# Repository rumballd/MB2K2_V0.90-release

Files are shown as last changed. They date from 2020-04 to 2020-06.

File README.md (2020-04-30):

# MB2K2_V0.90 release

Microbox 2K2 (MB2K2). 

The MB2K2 is a hardware based emulator built around the Xmos XU216 SoC where each of the 16 RISC cores in the SoC map onto the individual LSI chips of the system being emulated, CPU, PIA, ACIA, RTC etc. The PCB has VGA based video together with a PS/2 keyboard interface and USB for power and two virtual serial ports to a host computer. 

Initially I’ve used it to emulate an old 1982 era 6809/Flex single board computer design of mine (Microbox 2) but there’s nothing to stop the emulation of other processors and LSI devices by using a low cost JTAG interface and free toolchain from Xmos. If enough folks are interested I should be able to order a batch of blank PCBs.

The hardware is complete and the initial firmware supports:-

* MC6809 processor emulation running at approx 8MHz equiv (ie 4x faster than the original)
* 64KB of 6809 RAM with MON09 and Flex in ‘ROM'
* 200KB ramdisk + 1MB+ promdisk
* WD2123 DUART emulation with twin serial ports to the host computer as VCPs via USB, one can be used with FlexNet for remote storage
* MC146818 RTC emulation via a physical battery backed RTC/PRAM on the PCB
* MC6821 PIA emulation for the MB2’s bell and option switches and PS/2 keyboard interface (replaces the MB2’s parallel keyboard)
* uPD7220A hardware graphics accelerator emulation with output as 768x576 ‘VGA’
* PS/2 keyboard interface 

Not in the initial release but ‘hardware ready’ is a 3 1/2” floppy disk interface emulating the WD1770 FDC.

This all fits on a 80x80mm double sided 4 layer PCB which is designed to be assembled by hand (few fine pitch components etc).

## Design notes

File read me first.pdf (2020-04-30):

Version 0.9 30th April 2020

### Microbox 2K2 distribution 0.9 April 2020

This package should contain the following folders :-

* docs | - MB2K2 user notes, quick start guide and FLEX manuals.
* firmware | - XU216 firmware project, data sheets and app notes.
* hardware | - PCB fabrication files and component data sheets.
* MB2K2 source | - 6809 source plus MB2K2_SRC and PROMdisk disk images.

History
2020-04-30 | ver 0.9 | First release to the outside world.

Known Issues

Todo List

This early release of the MB2K2 firmware is fully functional and runs the MB2 graphics demo software, but there are some unfinished parts and in later releases I hope to :-

- Improve the documentation!
- Improve the uPD7220A emulation for greater compatibility with MB2 software.
- Port the schematic/PCB design from Altium into KiCad so that the hardware can be changed with free and open source tools.
- Implement the WD170 floppy disk controller

This project does not contain polished or shipping quality code, so use entirely at you own risk. As this is the first release there may be some unknown dependences on my particular build environment.

The project is covered under the permissive version of the CERN Open Hardware Licence Version 2 a copy of which is part of the package.

If you have any problems with the build, find any bugs, have suggestions for features and improvements etc, please email me at david@rumball.org.uk

Have Fun!

David Rumball
Hinxworth, UK.

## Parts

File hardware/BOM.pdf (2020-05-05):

Designator | Descrip-on | Manufacturer | ManufacturerPN | Quan-ty
BT1 | CR1225 coin cell holder | Keystone | 3001 | 1
C1, C3, C5 | 4.7uF 0805 Ceramic Capacitor, 10%, 25V | Generic | | 3
C2, C7, C9, C10, C13, C14, C17, C18, C19, C20, C21, C22, C23, C24, C25, C26, C27, C28, C29, C30, C32, C33, C34 | 100nF 0805 Ceramic Capacitor, 10%, X5R, 25V | Generic | | 23
C4 | 2.2uF 0805 Ceramic Capacitor, 10%, 25V | Generic | | 1
C6 | 22uF 0805 Ceramic Capacitor, 10%, 6.3V | Generic | | 1
C8 | 10nF 0805 Ceramic Capacitor, 20%, X7R, 50V | Generic | | 1
C11, C12 | 4p7 0805 Ceramic Capacitor, 50V | Generic | | 2
C15, C16 | 1nF 0805 Ceramic Capacitor, 5%, 50V | Generic | | 2
C31 | 1uF 0805 Ceramic Capacitor, 10%, 16V | Generic | | 1
C35 | 100p 0805 Ceramic Capacitor, 50V | Generic | | 1
CN1 | Box header 2.54mm Ver-cal 20 way | Molex | 70246-2004 | 1
D1 | LED 0805 White | Generic | | 1
D2, D4, D6 | LED 0805 Red | Generic | | 3
D3, D5, D7 | LED 0805 Green | Generic | | 3
D8 | LED 0805 Blue | Generic | | 1
D9 | Dual ESD protec-on diode SMD | Nexperia | PRTR5V0U2X,215 | 1
D10 | Diode SchoXky, 1A, 40V, SOD-123-2 | ON Semiconductor | SS14FL | 1
J1 | VGA HD-25 connector RA through hole | EDAC | 634-015-274-992 | 1
J2 | MIni DIN 6 pin through hole | TE | 5749180-1 | 1
J3 | Box header 2.54mm Ver-cal 34 way | Molex | 70246-3404 | 1
J4 | USB type B connector RA through hole | Mul-comp | USB-B-S-RA | 1
J5 | Ver-cal Pin Header Pitch 0.1", Single Row, 3 pins | Wurth Elektronik | 61300311121 | 1
L1 | Inductor, Mul-layer, 2.2uH, 3.1A Isat, SMD | Vishay Dale | IFSC1515AHER2R2M01 | 1
LS1 | 3V Buzzer through hole | IMO | 41.S78P030A-LF | 1
P1, P2 | Ver-cal Pin Header Pitch 0.1", Single Row, 5 pins | Wurth Elektronik | 61300511121 | 2
R1, R2, R3, R4, R17, R27, R35, R36, R39 | 330R 0805 Chip Resistor | Generic | | 9
R5, R9, R14, R40, R42 | 4K7 0805 Chip Resistor | Generic | | 5
R6 | 17K8 0805 Chip Resistor | Generic | | 1
R7 | 3K0 0805 Chip Resistor | Generic | | 1
R8, R13, R15, R16, R19, R21, R22, R23, R24, R25, R26, R38, R43, R44, R45, R48 | 10K 0805 Chip Resistor | Generic | | 16
R10, R41 | 100K 0805 Chip Resistor | Generic | | 2
R11, R12, R18, R20, R28 | 1K0 0805 Chip Resistor | Generic | | 5
R29, R31, R33, R49, R58, R59 | 33R 0805 Chip Resistor | Generic | | 6
R30, R32, R34 | 100R 0805 Chip Resistor | Generic | | 3
R37, R46, R51, R55, R56, R57 | 0R 0805 Chip Resistor | Generic | | 6
R47 | 4R7 0805 Chip Resistor | Generic | | 1
R50 | 43R 0805 Chip Resistor | Generic | | 1
R52, R53, R54 | 75R 0805 Chip Resistor | Generic | | 3
SW1 | 4 way DIP switch, through hole | CTS | 210-4MS | 1
SW2 | Tac-le Switch, SPST-NO, 0.05A, 12V | E-Switch | TL1014AF160QG | 1
TR1, TR2, TR3 | N Channel MOSFET 20V SOT23 | Taiwan Semiconductors | TSM2302CX | 3
U1 | SP6205EM5-L-3-0 500mA Low Dropout Voltage Regulator | Exar | SP6205EM5-L-3-3/TR | 1
U2 | Switching regulator, 1.5 A, adjustable, step-down, 6-Pin DFN | STMicroelectronics | ST1S06PUR | 1
U3 | xCORE-200 XU series 512 kB RAM TQFP128 | XMOS | XU216-512-TQ128-C20 | 1
U4 | Memory, Flash, QSPI, 32Mb, SOIC-8 | ISSI | IS25LQ032B-JNLE | 1
U5 | Voltage Detector, 0.9V, Programmable Delay, OD, SOT23-5 | ON Semiconductor | NCP303LSN09T1G | 1
U6 | BaXery-Backed I2C RTC + SRAM & EEPROM | Microchip | MCP79410-I/SN | 1
U7, U8 | Hex OD buffer SOIC-14 | Texas Instruments | SN74LVC07AD | 2
U9 | Quad Buffer 3-State SOIC-14 | Texas Instruments | SN74LVC125AD | 1
X1 | SMD Crystal, 32.768kHz | Epson Toyocom | FC-135 32.7680KA-AC | 1
X2 | XTAL Osc XO 24MHz CMOS | Abracon LLC | ASE-24.000MHZ-LC-T | 1

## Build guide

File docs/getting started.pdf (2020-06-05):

Microbox 2K2 User Guide | Version 0.9 30th April 2020

### Microbox 2K2 ‘getting started’ guide

Introduction

This guide covers the initial set up and basic operation of the Microbox 2K2 (MB2K2) including the installation of the Xmos xTIMEcomposer toolchain which is used to flash and reprogram the system.

The MB2K2 is based around a single PCB that carries the circuitry for the complete system requiring only the addition of a 5V USB power supply, standard PS/2 compatible keyboard and VGA monitor. Alternatively the MB2K2 may just be plugged into the USB port of a host computer with a terminal application running on the host providing the user interface.

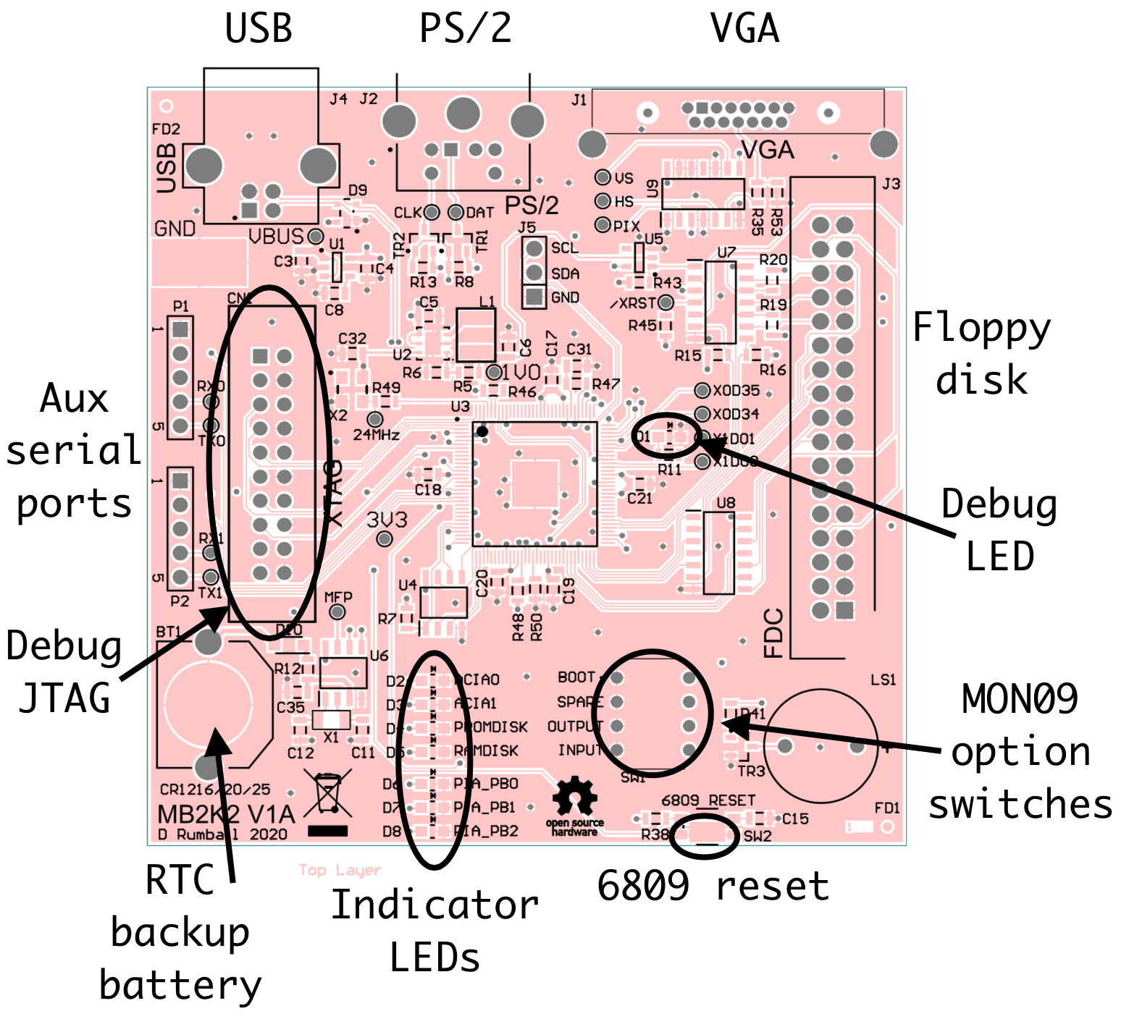
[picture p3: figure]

Connector, switches and LED locations

Initial set up

The MB2K2 is powered entirely via it’s USB connector and requires a notional 5V supply at a maximum of 250mA (approx 150mA nominal) to its ‘type B’ connector. This is well within the capability of most standard computer USB ports. If the MB2K2 is to be used stand alone without a host connection a standard USB charger may be used instead.

If the MB2K2 is connected to a host computer for power and control then no further set up is required other wise a standard PS\2 style keyboard and VGA compatible monitor need to be connected. Note that the keyboard is powered directly from the board’s USB port and so the keyboard will increase the power draw of the system. The horizontal display rate of the MB2K2 is approximately 35KHz and the frame rate 56Hz which should be compatible with the majority of modern monitors.

The MB2K2 uses a battery backed real time clock for time date and persistent storage of settings. The battery is a standard 3V Lithium coin cell and the battery holder can accept CR1216 CR1220 or CR1225 batteries.

Before first powering on, set the MON09 option switches according to the required input and display and set switch 0 ‘off’ so that the system starts up in MON09.

Switch 0 | Sets the auto boot function. on = Auto boot into FLEX on reset off = run MON09 on reset
Switch 1 | (not used in this build)
Switch 2 | Sets the initial output port to be used after reset on = PORT 1 (serial port 0) - USB off = PORT 0 (GDC screen)
Switch 3 | Sets the initial input port to be used after reset on = PORT 1 (serial port 0) - USB off = PORT 0 (PS/2 keyboard)

After applying power if all is well then the display should show the MON09 startup banner followed by the command prompt and a flashing cursor:-

+++ MON09 Ver 6.0 D.A.Rumball 2020 +++
=>

Note that if this is the first power up after inserting the battery or if the battery is not present then a warning will be shown and the default settings loaded into the RTC.

At the MON09 prompt a two character command can be issued and these commands are detailed in section 5 of the user guide.

To boot into FLEX type ‘BO’, FLEX will be loaded, the ‘TTYSET’ and ‘ASN’ parameters will be set, the time and date shown and the FLEX ‘+++’ prompt will appear. Note that if switch 3 of the option switches is ‘on’ then the MB2K2 will boot immediately into FLEX on power up.

The standard firmware of the MB2K2 includes a pre-installed PROMdisk of FLEX commands and utilities and the PROMdisk contents are detailed in appendix 6 of the User Guide. The default work disk is a (volatile) RAMdisk. Further disk images may be connected via USB and FlexNet.
FlexNet and remote disk images

The MB2K2 has drivers in ROM that are compatible with the FlexNet protocol. FlexNet allows FLEX disk images on a computer connected to the MB2K2 via USB to look like a disk drive to FLEX. To use this facility it’s necessary to install the FlexNet server software on the connected system. The FlexNet software for windows can be downloaded from http://www.evenson-consulting.com/. (http://www.evenson-consulting.com/) Details of the FLEX utilities that work with FlexNet are given in section 6 of the user guide.

Presently FlexNet is only available for Windows only but the plan is to ship cross platform versions of the FlexNet server etc in a later version of the MB2K2 release.

Building and flashing the firmware

Flashing the MB2K2’s firmware requires the installation of the free Xmos xTIMEcomposer toolchain (version 14.4.1) and obtaining an ‘XTAG’ (https://www.xmos.com/download/xTAG-3-Hardware-Manual(1.0).pdf) USB debug interface. The toolchain may be downloaded directly from Xmos at the tools download (https://www.xmos.com/software/tools/) page and the XTAG interface is readily available from several suppliers world wide for about $20, see Octopart (https://octopart.com/xa-xtag-xmos-52441747?r=sp) for details.

Documentation for the xTIMEcomposer tools is in the ‘data sheets & app notes etc’ folder in the firmware folder and covers importing project, the IDE, building the project and flashing. Details on building MON09 and modifying other parts of the MB2K2 firmware may be found in section 4 of the MB2K2 User Guide.

The MB2K2 can be flashed from xTIME composer or the command line tools but whichever route is taken it is necessary to specify these options:-

--no-compression
--boot-partition-size 0x100000
--data <location of promdisk.dsk file>

In the default build, the binaries (.xe files) are in the ‘release’ and ‘debug’ folders in the ‘bin’ folder in the firmware project folder whilst the PROMdisk disk image is in the ‘promdisk’ folder.

A more detailed set of instructions for building and flashing the firmware can be found in the ‘Firmware Build and Flashing Guide’ contained in the documentation folder.

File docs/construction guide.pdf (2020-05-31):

Version 0.9 30th April 2020

### Microbox 2K2 Construction guide

Introduction

This document contains some brief notes to assist during the assembly of the MB2K2 PCB. It assumes that the reader has some experience with fine pitch SMD soldering, if not don’t panic as there are any number of online resources and YouTube videos that go over the basics.

As with all SMD assembly it’s important to follow good safety procedures particularly to ensure that you have good protection from the fumes generated from soldering and from any hot solder splashes, again there is a wealth of online information concerning protection from these and other hazards, follow it!

The tips and suggestions below are intended to be guidelines and don’t need to be followed slavishly, if you have a better way of doing things then by all means use it.

The PCB has been designed with an eye towards manual assembly and has a number of features to simplify the process. It’s entirely possible to assemble the board using just a temperature controlled soldering iron and without needing to use a hot air gun or reflow plate.

BOM
The component BOM is given in the hardware folder of the release package. For convenience it’s also accessible as a shared ‘live’ BOM on Octopart. (https://octopart.com/bom-tool/GZSDr5Fk) At the time of writing all the components are really available and the total BOM cost is < $50.

Construction notes

- R51 is no fit
- R55-57 are optional components
- The surface finish of the PCB is ENIG (https://en.wikipedia.org/wiki/Electroless_nickel_immersion_gold) as this eases the soldering of the fine pitch components. With this finish it’s important to clean the PCB thoroughly before assembly and to use a good quality flux. I’ve found that one of the no clean ‘gel’ fluxes gives the best results.
- Assemble the 3.3V and 1.0V power power supply components first and test that these are working correctly before proceeding with the rest of the assembly. This can save some expensive problems later on. The switch mode regulator chip U2 has a ‘hidden’ ground pad underneath its package. So that this device can be attached without reflow there is a large via in the PCB underneath the parts and this allows the hidden pad to be soldered from the bottom of the PCB. This feature also has the side effect of forming a good heat sink to the inner layers of the PCB although in practice this isn’t needed as the design runs very cool in use as this thermograph shows:-

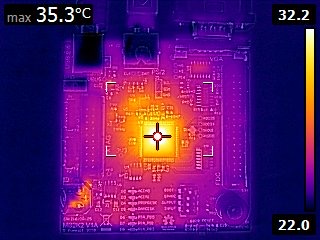
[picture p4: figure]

- The XU216 should be added next, this is probably the most difficult part. Be sure to leave the XU216 in its moisture sealed packaging until just before assembly as the part is prone to ‘popcorning’ (https://en.wikipedia.org/wiki/Moisture_sensitivity_level) if left in a humid atmosphere too long. The leads of this part are quite fragile, if possible handle just with a vacuum pencil (http://www.apple.com/uk) to avoid touching the leads.

Use plenty of flux; this is where the gel flux is handy because it holds the part in place but still allows fine adjustments of position. (Don’t forget to put some flux on the ground pad in and around the via). Check that pin 1 is in the correct place! (there is a flat corner and depression marking on the part and a dot on the PCB to show the location of pin one). When the part is correctly positioned, tack down one lead near a corner and check the alignment again, if ok tack a pin on the opposite corner.

Because of the fine pitch of the leads on the part, the best way to solder the leads isn’t to use the traditional technique of applying the solder to the joint, instead it’s better to apply a small amount of solder to the iron tip and apply this to the very end of the pin allowing the solder to wick along the pad to form the joint. The PCB features solder mask slivers between the pads (this would not normally be a good idea in a mass production PCB) which helps discourages the solder from bridging between pins and if any solder bridges do form the solder mask assists clearing these with solder wick.

In the same manner as the switch mode regulator the XU216 has a hidden pad underneath the device which is its only connection to ground. This pad carries all of the logic and I/O current so it’s important to ensure that a good connection is made. As before there is a large via which is used to allow access to the ground pad from the rear of the PCB so when the signal leads are soldered then the ground connection can be made. Use plenty of flux here and flood solder into the via. Heat will tend to flow into the internal planes of the PCB so use a hot iron and beware of forming a ‘cold’ solder joint. When complete it should look something like this :-

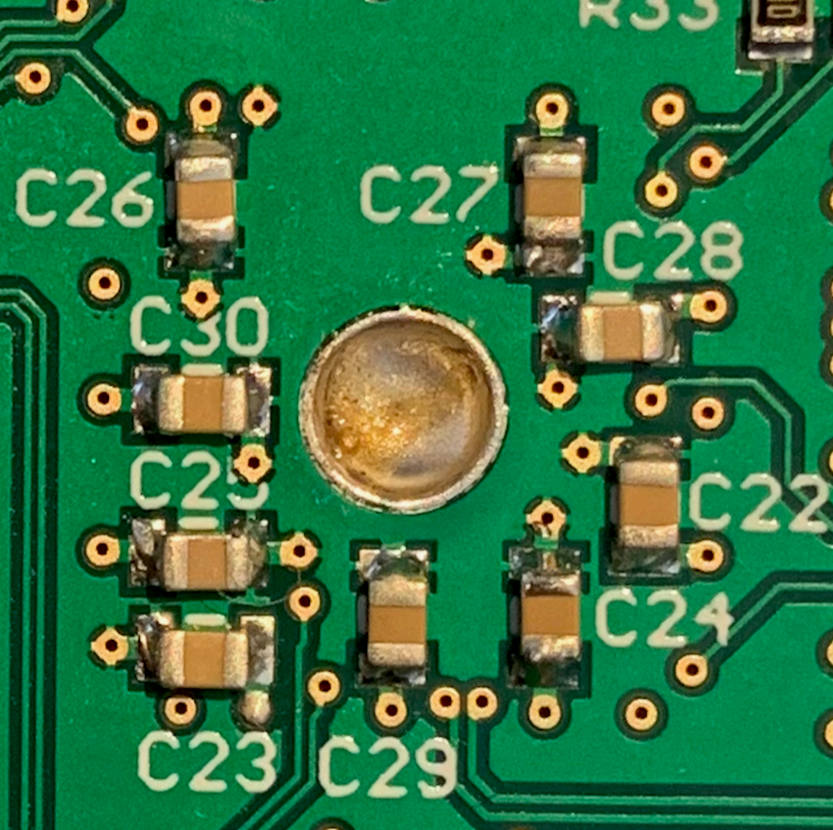
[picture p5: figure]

- After the XU216 is in place, place the other SMD components. For the discrete parts flux both pads then tin one of the pads. Then slide the part into place with fine point tweezers whilst melting the solder to make the first joint and then solder the other end. In practice this takes less time to do than to describe. I find that it’s easiest to work down the BOM placing all the instances of a particular component value in one pass.
- After placing the SMD parts place the through hole parts last of all and give the PCB a good clean with IPA and an old toothbrush.

Initial testing

- Don’t install the battery until after the firmware is flashed.
- Briefly apply power to the board and check current draw, it should be in the region of 100mA - 150mA, much greater than this indicates a short somewhere or a reversed IC. If the initial ‘smoke test’ is OK check that the 3.3V and 1V power rails are correct.
- If a scope is available check that the 24MHz clock is present and that reset is asserted following power up.

Flashing the firmware

Flashing the MB2K2’s firmware requires the installation of the free Xmos xTIMEcomposer toolchain (version 14.4.1) and obtaining an ‘XTAG’ (https://www.xmos.com/download/xTAG-3-Hardware-Manual(1.0).pdf) USB debug interface. The toolchain may be downloaded directly from Xmos at the tools download (https://www.xmos.com/software/tools/) page and the XTAG interface is readily available from several suppliers world wide for about $20, see Octopart (https://octopart.com/xa-xtag-xmos-52441747?r=sp) for details.

Documentation for the xTIMEcomposer tools is in the ‘data sheets & app notes etc’ folder in the firmware folder and covers importing project, the IDE, building the project and flashing. It may be also necessary to install the Java runtime

Download the latest MB2K2 release package from GitHub, (https://github.com/rumballd/MB2K2_V0.90-release.git) unzip the project folder located in MB2K2_V0.90-release-master\firmware and locate the binary images in MB2K2\bin within the project.

Power on the MB2K2 and connect the XTAG to the board. (the XTAG may be safely connected or disconnected to a powered MB2K2) then open up the Xmos command line interface installed as part of xTIMEcomposer in the earlier step and use the following command:-

xrun -l

This command looks for the XTAG connector then reports on the connected device. The command should report something like :-

Available XMOS Devices
ID | Name | Adapter ID | Devices
0 | XMOS XTAG-3 | ZByhc2hJ | O[0]

if the command reports ‘none’ for the devices then there is a hardware fault with the board. If the power supplies and 24MHz clock are OK then this will most likely be an issue with a bad solder joint on the XU216 so check the pin connections and the ground connection under the PCB.

If all is well then the firmware may be flashed with the ‘xflash’ command thus:-

xflash -—verbose -—no-compression -—factory <image.xe> --boot-partition-size 0x80000 --data <promdisk.dsk>

where
<image.xe> is the path to the image file
use MB2K2\bin\mb2k2_debug_usb.xe as the default

<promdisk.dsk> is the path to the promdisk image
use MB2K2/promdisk/MB2K2PD.dsk as the default

After about 30 seconds or so the flashing will begin with a series of messages of the form ‘site 0 write’ followed by an incrementing address as each flash block is written. With the current build and promdisk the block address will run up to about 0x00110500.

After the flashing process is complete the MB2K2 will restart and you should see the debug LED (to the right hand side of the XU216) flashing on and off in a ‘breathing’ pattern. This is the sign that the firmware is working correctly. Power down and insert the battery (noting polarity).

Congratulations on a successful build!

Connect a VGA compatible monitor and PS/2 keyboard and boot into FLEX with the ‘BO’ command in MON09 then set the current date and time with the SETTIME command.

This completes the initial testing of your MB2K2, so make yourself a nice cup of tea (or whatever you prefer), sit down with your feet up, type DEMO and watch the pretty graphics!

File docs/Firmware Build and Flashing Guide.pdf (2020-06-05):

Microbox 2K2 User Guide | Version 0.9 30th April 2020

### MB2K2 Firmware Build and Flashing Guide

Introduction

This guide covers the installation of the Xmos xTIMEcomposer toolchain which is used to flash and reprogram the system together with a walkthrough on building the firmware and flashing this to the hardware.

Prerequisites

In order to talk to the XU216’s JTAG interface for debugging and programming the on board flash memory it will be necessary to obtain an Xmos ‘XA-XTAG’ USB debug adaptor. These are really available from component distributors such as Digi-Key for about $20. Octopart has a list of distributors and stock here. (https://octopart.com/xa-xtag-xmos-52441747?r=sp) The XTAG plugs vertically into the 20 pin header on the MB2K2 PCB.

Step by step guide

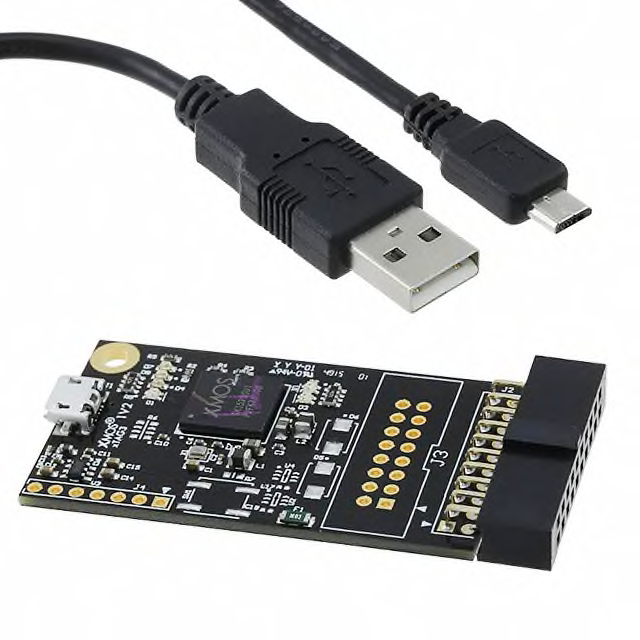
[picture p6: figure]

It’s recommended to use Windows 10 for firmware development on the MB2K2.
1) Download and install version 14.4.1 of the Xmos xTIMEcomposer toolchain from here. (https://www.xmos.com/software/tools/) the 14.4.1). You will need to register for a free account, make a note of the username/password as these will be used later.

Run the installer and except all the default options. At the end of the process there should be icons on the desktop for the xTIMEcomposer command prompt, the IDE and a link to documentation.

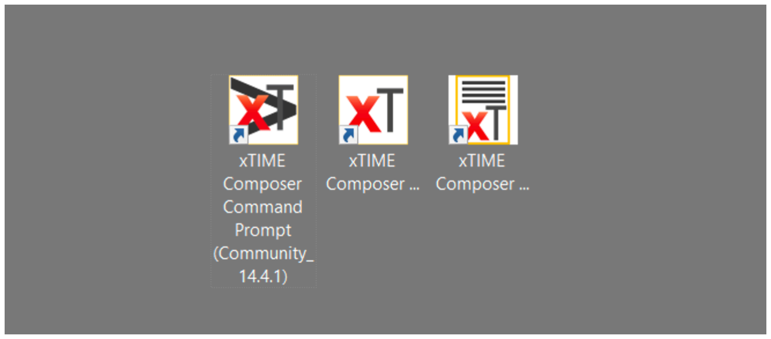
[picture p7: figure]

2) Go to the HackaDay page for the MB2K2 project here (https://hackaday.io/project/171289-microbox-2k2) and follow the link for the MB2K2_V0.90-release. Download the latest version of the distribution using the ‘clone or download’ button or if preferred clone the repository instead.

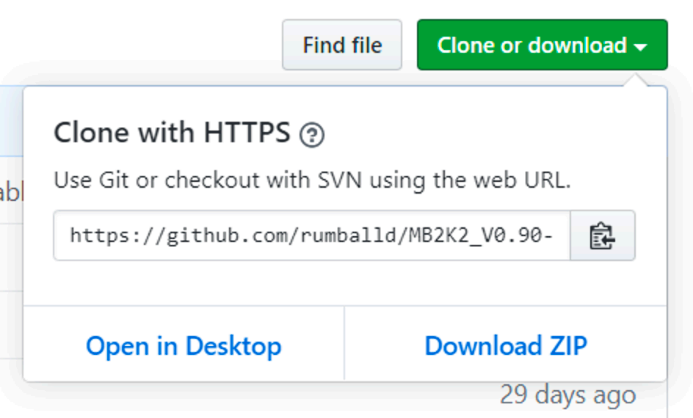
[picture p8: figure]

Unzip the dowloaded file to a convenient location, the contents of the unzipped folder should be something like this :-

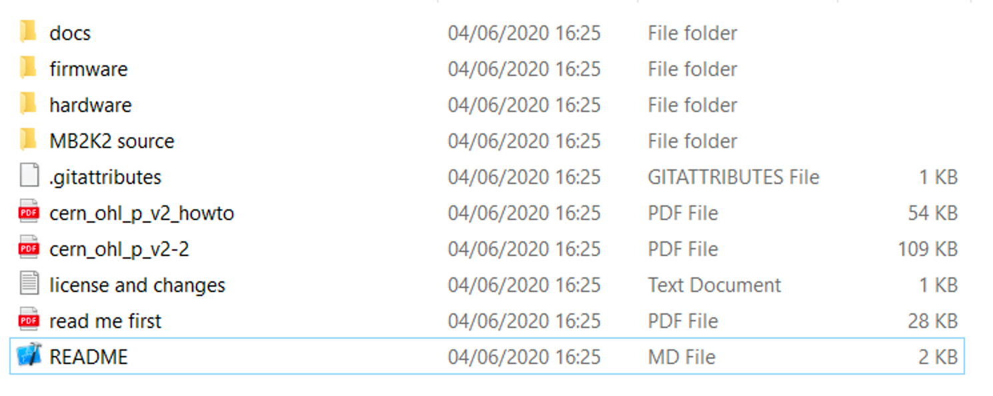
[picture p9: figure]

Note that there is documentation for xTIME composer in the ‘firmware/data sheets & app notes etc’ folder in the documentation.

3) Run the xTIME Composer Studio (Community_14.4.1) application (IDE). Note that the IDE needs a 32 bit Java Runtime Environment (JRE) to be installed. Once the IDE has started accept the default workspace location and sign in using the credentials for your Xmos account. Then close the ‘XMOS Welcome’ tab and select the ‘edit’ perspective. At this point the window should look something like this :-

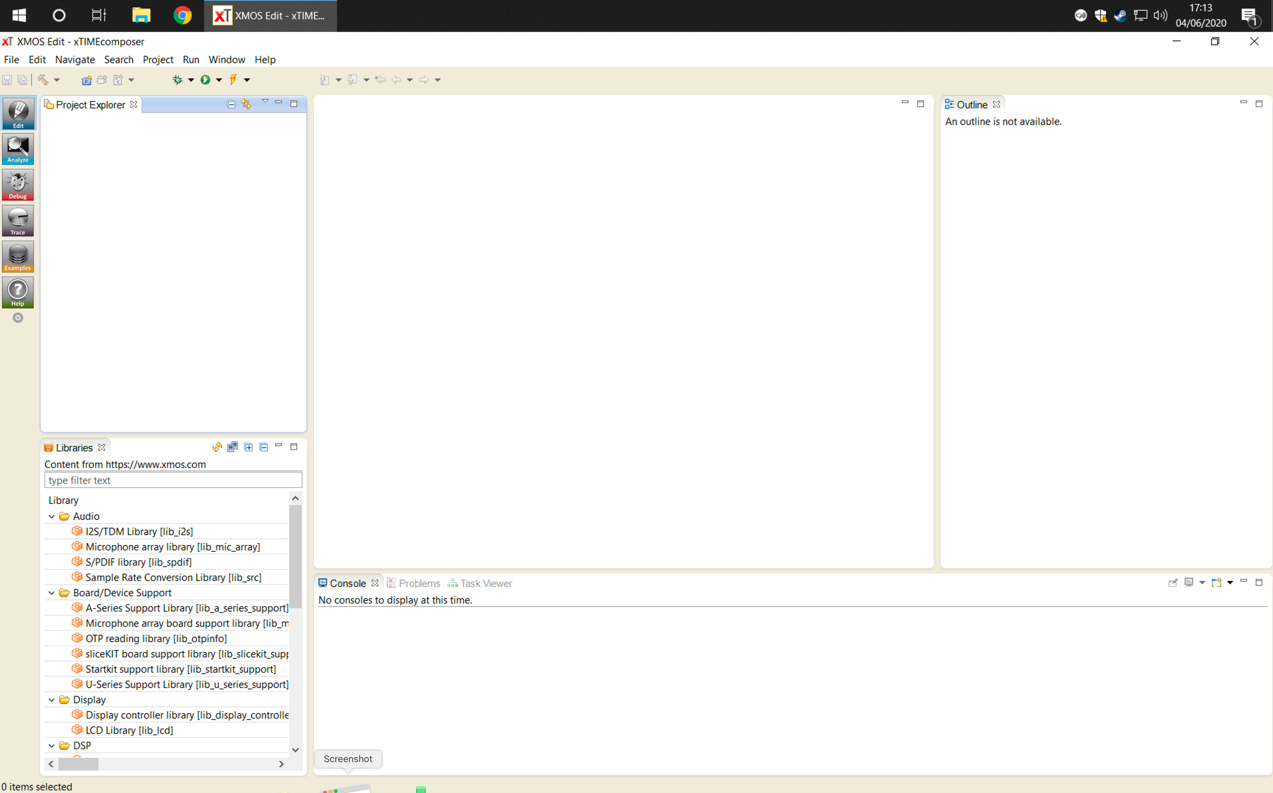
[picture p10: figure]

4) Import the MB2K2 project. Select ‘import’ from the file menu, then expand the ‘general’ folder icon and select ‘Existing Projects into Workspace’ then hit ‘next’.

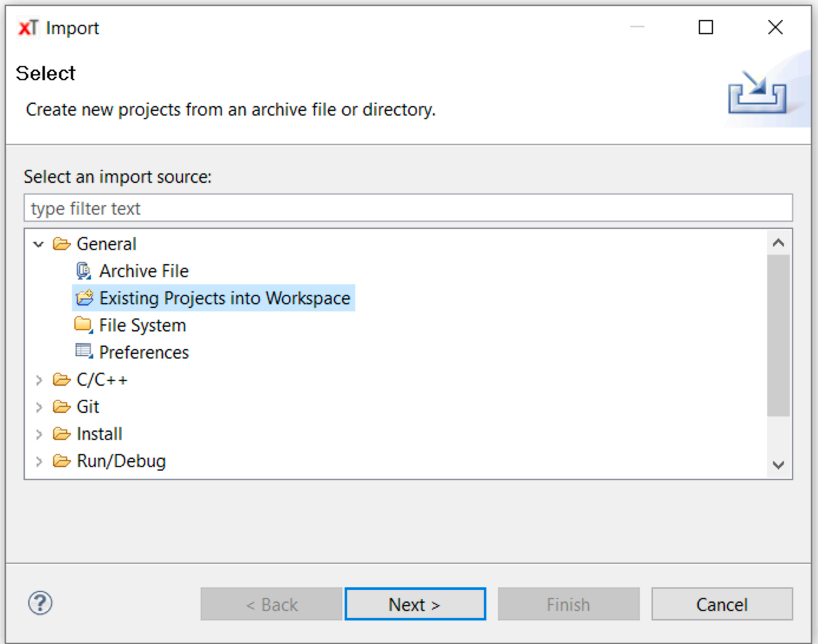
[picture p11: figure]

Select the ‘archive file’ option and browse to the project archive in the ‘firmware’ folder in the MB2K2 distribution package and select ‘open’. There will now be a list of project modules looking something like this :-

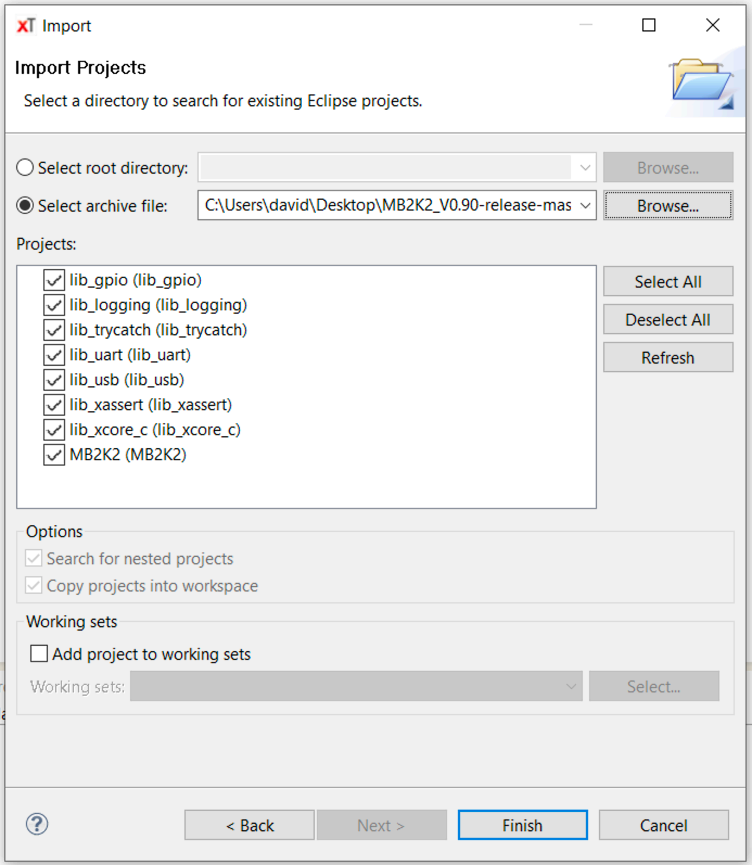
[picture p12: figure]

Hit ‘finish’ and the project will be imported into the workspace. The ‘project explorer’ tab should now look like this :-

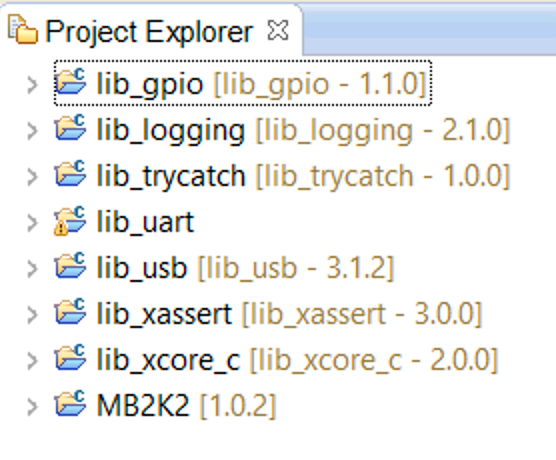
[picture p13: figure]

The source file structure consists of a number of Xmos lib projects together with the MB2K2 source folder :-

- boot image and build tools
- drivers for USB CDC class for Windows7
- MON09 source code and build tools
- promdisk image DSK (used by xFLASH)
- serial port source
- 6809 source
- uPD7220 source
- 6821 and PS/2
- PROMdisk source
- decode/RAM handler source
- RAMdisk source
- RTC and I2C interface source
- XUD USB interface source
- hardware description file

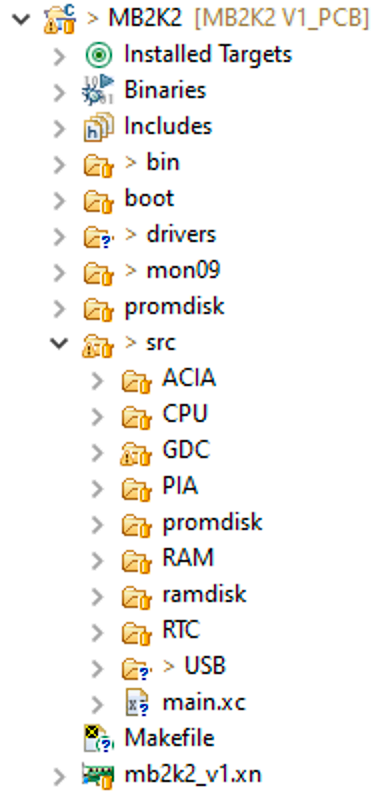
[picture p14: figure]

The use of the IDE for editing the code is outside the scope of this document but full details can be found in the ‘xTIMEcomposer’ User Guide which can be found in the ‘firmware/data sheets & app notes’ folder in the distribution.

5) Clean the project. Select ‘Clean…’ from the ‘Project’ menu. Select ‘clean all projects’ and unselect ‘Start a build immediately’ the hit ‘OK’. Only for the first time after the project is imported, clean the project a second time.

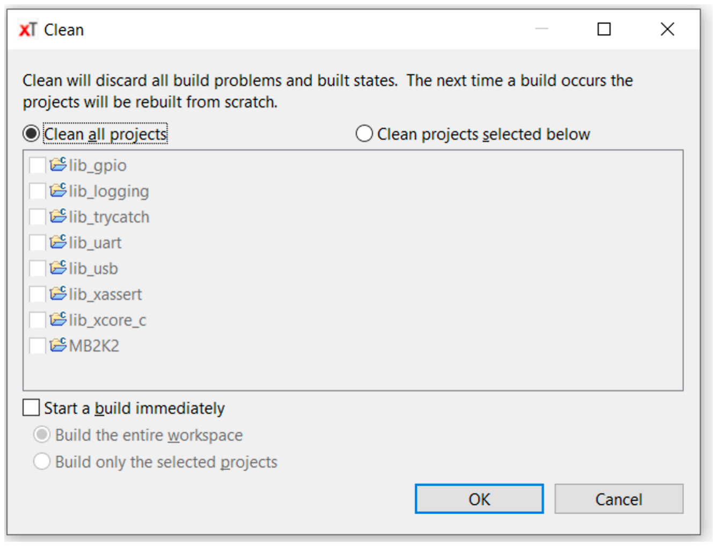
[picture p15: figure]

6) Build the project. Expand the ‘MB2K2’ and then ‘src’ folders and select ‘main.xc’. The build icon (hammer) in the toolbar will then become solid and a build configuration can be selected from the list.

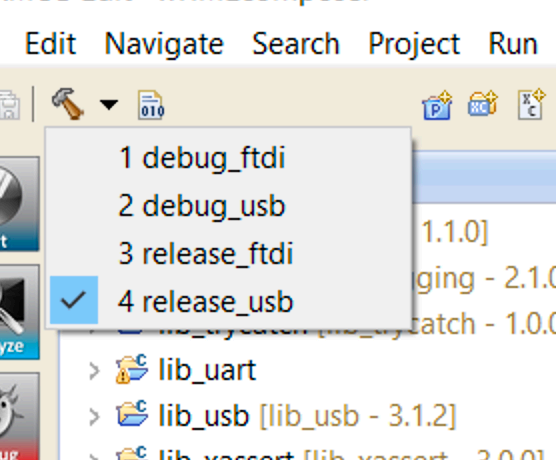
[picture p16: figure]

There are two classes of build configurations in the project, ‘usb’ which uses the USB connection for serial connections and ‘ftdi’ which replaces the USB interface with a pair of buffered UARTs. Each is further split into ‘debug’ which has optimisation set to -O0 and adds support for the use of debugPrintf() and ‘release’ which has optimisation set to -O3 and removes all debugging support.

The release configs should be used when not debugging as the compiled code runs 3-5 times faster than the debug configs!

For now, use the ‘release_usb’ configuration. Click on the pulldown arrow next to this and select ‘release_usb’ and the build will start.

Progress in the build will be shown and status messages/warnings/errors will appear in the Console tab at the bottom of the screen. With a fresh install there should be no errors and the warning messages can be safely ignored.

When the build is complete then a summary of the resource usage in the two XU216 tiles will be shown something like this :-

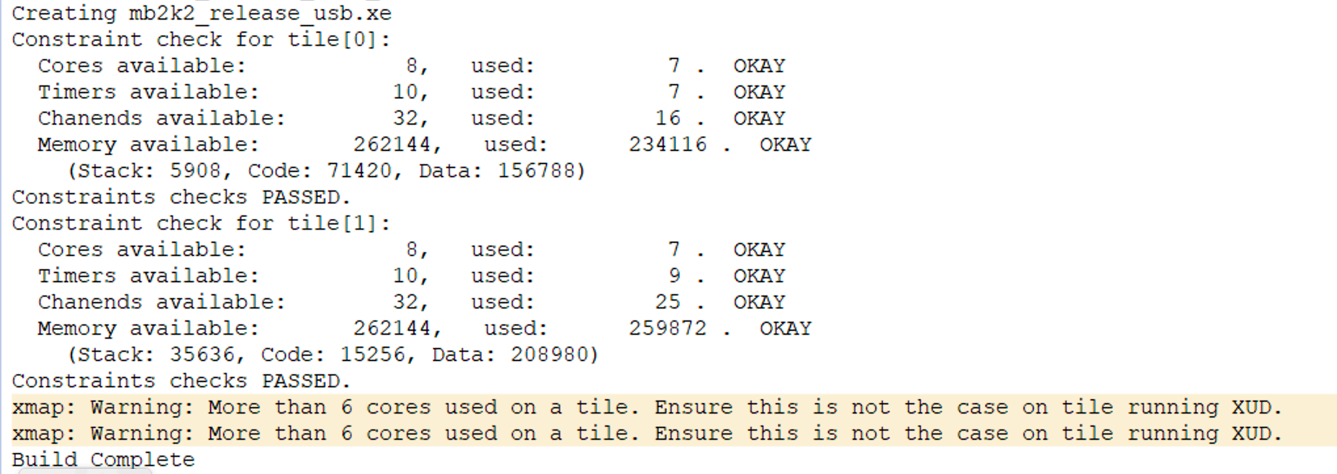
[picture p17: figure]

The map warnings can be ignored but note that the memory for the two tiles is quite full. This should be borne in mind when modifying the firmware. (see the Firmware notes in section 3 of the User Notes).

7) At this point the compiled binary may be loaded onto the hardware or placed into the flash memory and these operations will use the XA-XTAG adaptor to communicate with the XU216 via it’s JTAG interface. If not there already the XTAG should be plugged into the MB2K2 and it’s microUSB cable connected to the host computer. Note that it’s safe to connect and disconnect the XTAG when the MB2K2 is powered on providing that the usual precautions are taken to avoid static discharges.

Debugging and flashing the firmware

The ‘Debug’ toolbar icon (on the left hand side above) will load the compiled firmware onto the device’s RAM via the XTAG adaptor. Note that as this uses the RAM of the XU216 the firmware will be erased when power is removed. A configuration needs to be set up the first time debug is used. Hit the dropdown beside the debug button and choose ‘Debug Configurations…’, double click on ‘xCORE Application’ and name the new config. Many of the settings will be pre filled but it may be necessary in the ‘main’ tab to browse and select the project and application. Check that the XTAG is selected and showing that it is connected to the target device and lastly hit ‘apply’ to save the changes.

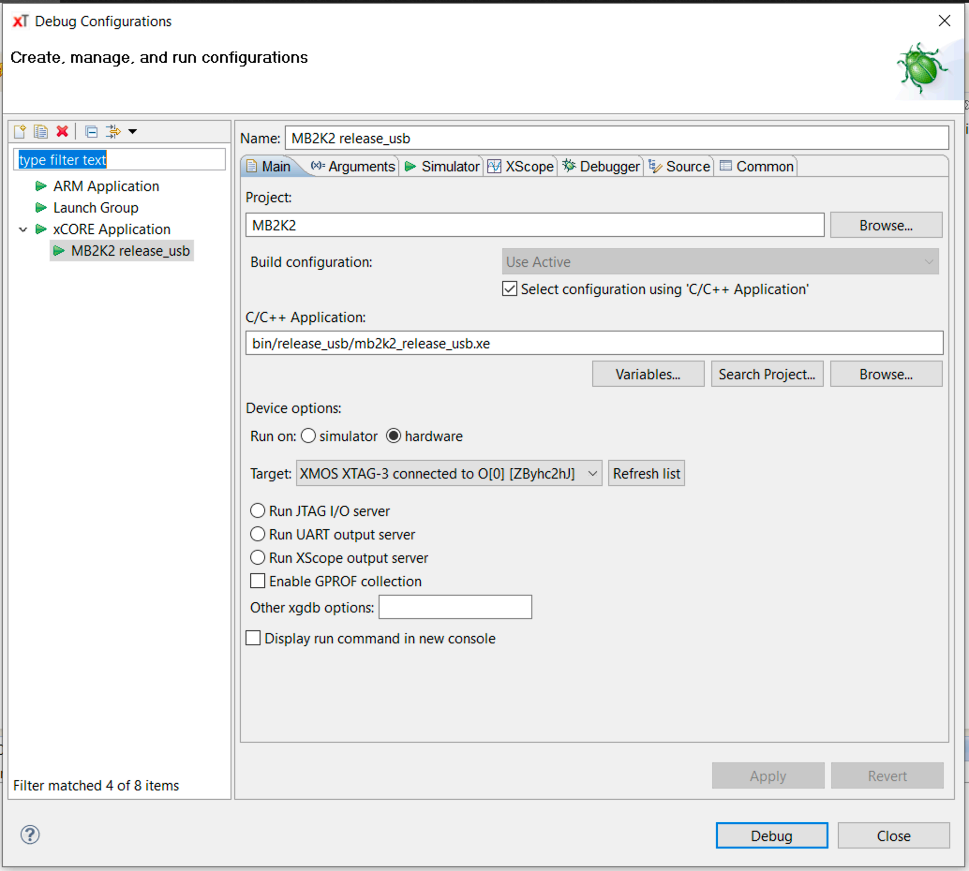
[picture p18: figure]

Now hit ‘Debug’, the console will show the code being loaded via the XTAG and the IDE will switch to the debug perspective. The use of the IDE for debugging is outside the scope of this document but full details can be found in the ‘xTIMEcomposer’ User Guide which can be found in the ‘firmware/ data sheets & app notes’ folder in the distribution.

In the same manner as debug, it is necessary to create a flash configuration before this function can be used. Hit the dropdown beside the ‘flash’ button and choose ‘Flash Configurations…’ then double click on ‘xCORE Application’ and name the new config. Unlike the debug config there are many settings to be specified for flashing. In the ‘main’ tab browse and select the project and application if necessary and check that the XTAG is selected and showing that it is connected to the target device. The ‘main tag of the config should look something like this :-

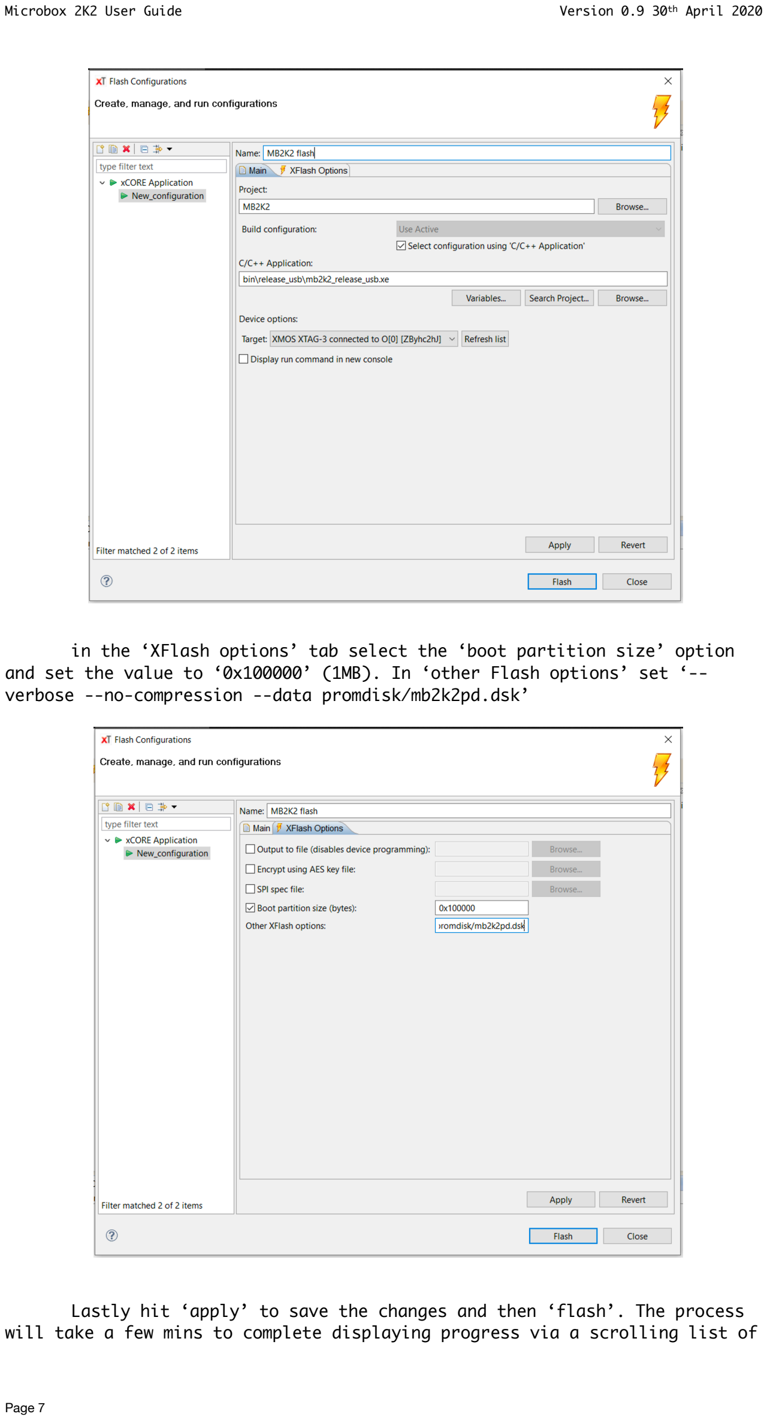
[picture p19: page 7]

in the ‘XFlash options’ tab select the ‘boot partition size’ option and set the value to ‘0x100000’ (1MB). In ‘other Flash options’ set ‘--verbose --no-compression --data promdisk/mb2k2pd.dsk’

Lastly hit ‘apply’ to save the changes and then ‘flash’. The process will take a few mins to complete displaying progress via a scrolling list of block addresses as each is written and verified. At the end, the MB2K2 should restart and the MON09 or FLEX prompts should appear.

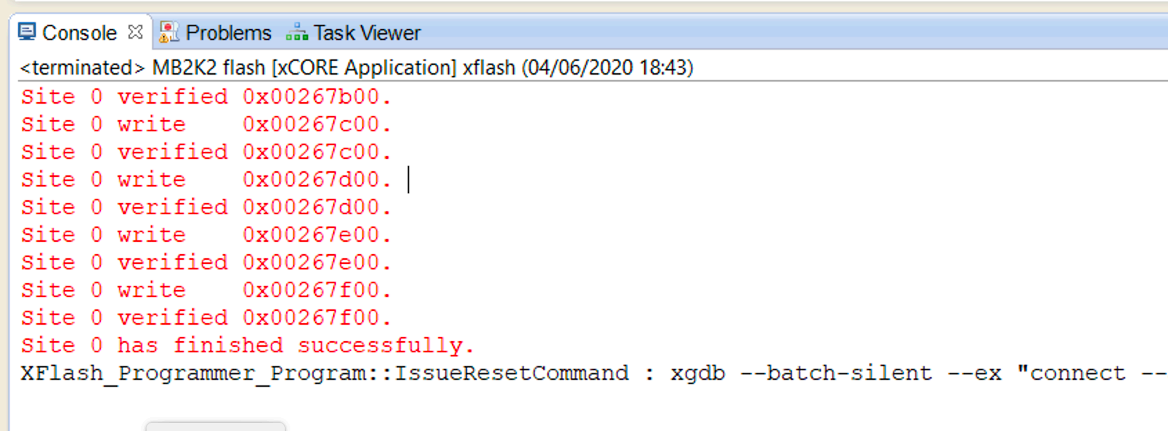
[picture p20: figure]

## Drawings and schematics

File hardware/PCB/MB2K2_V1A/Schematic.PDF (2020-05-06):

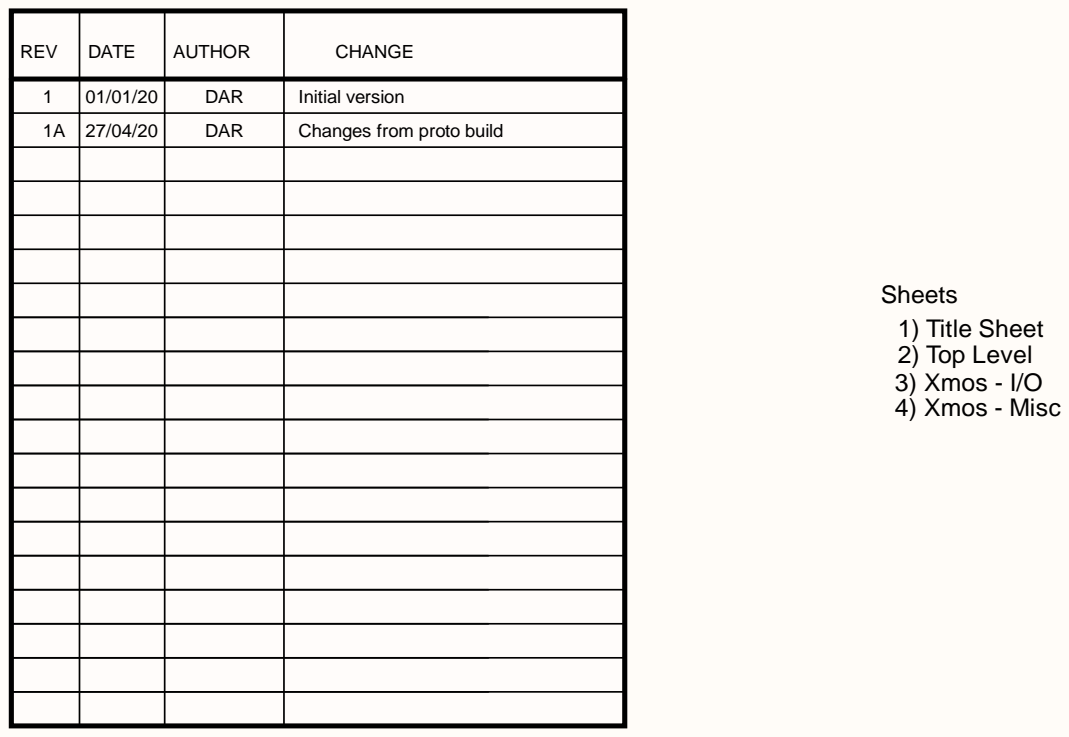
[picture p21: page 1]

REV | DATE | AUTHOR | CHANGE

1 | 01/01/20 | DAR | Initial version

1A | 27/04/20 | DAR | Changes from proto build

D:\MB2K2\Hardware\PCB\MB2K2_V1A\Title Sheet.SchDoc

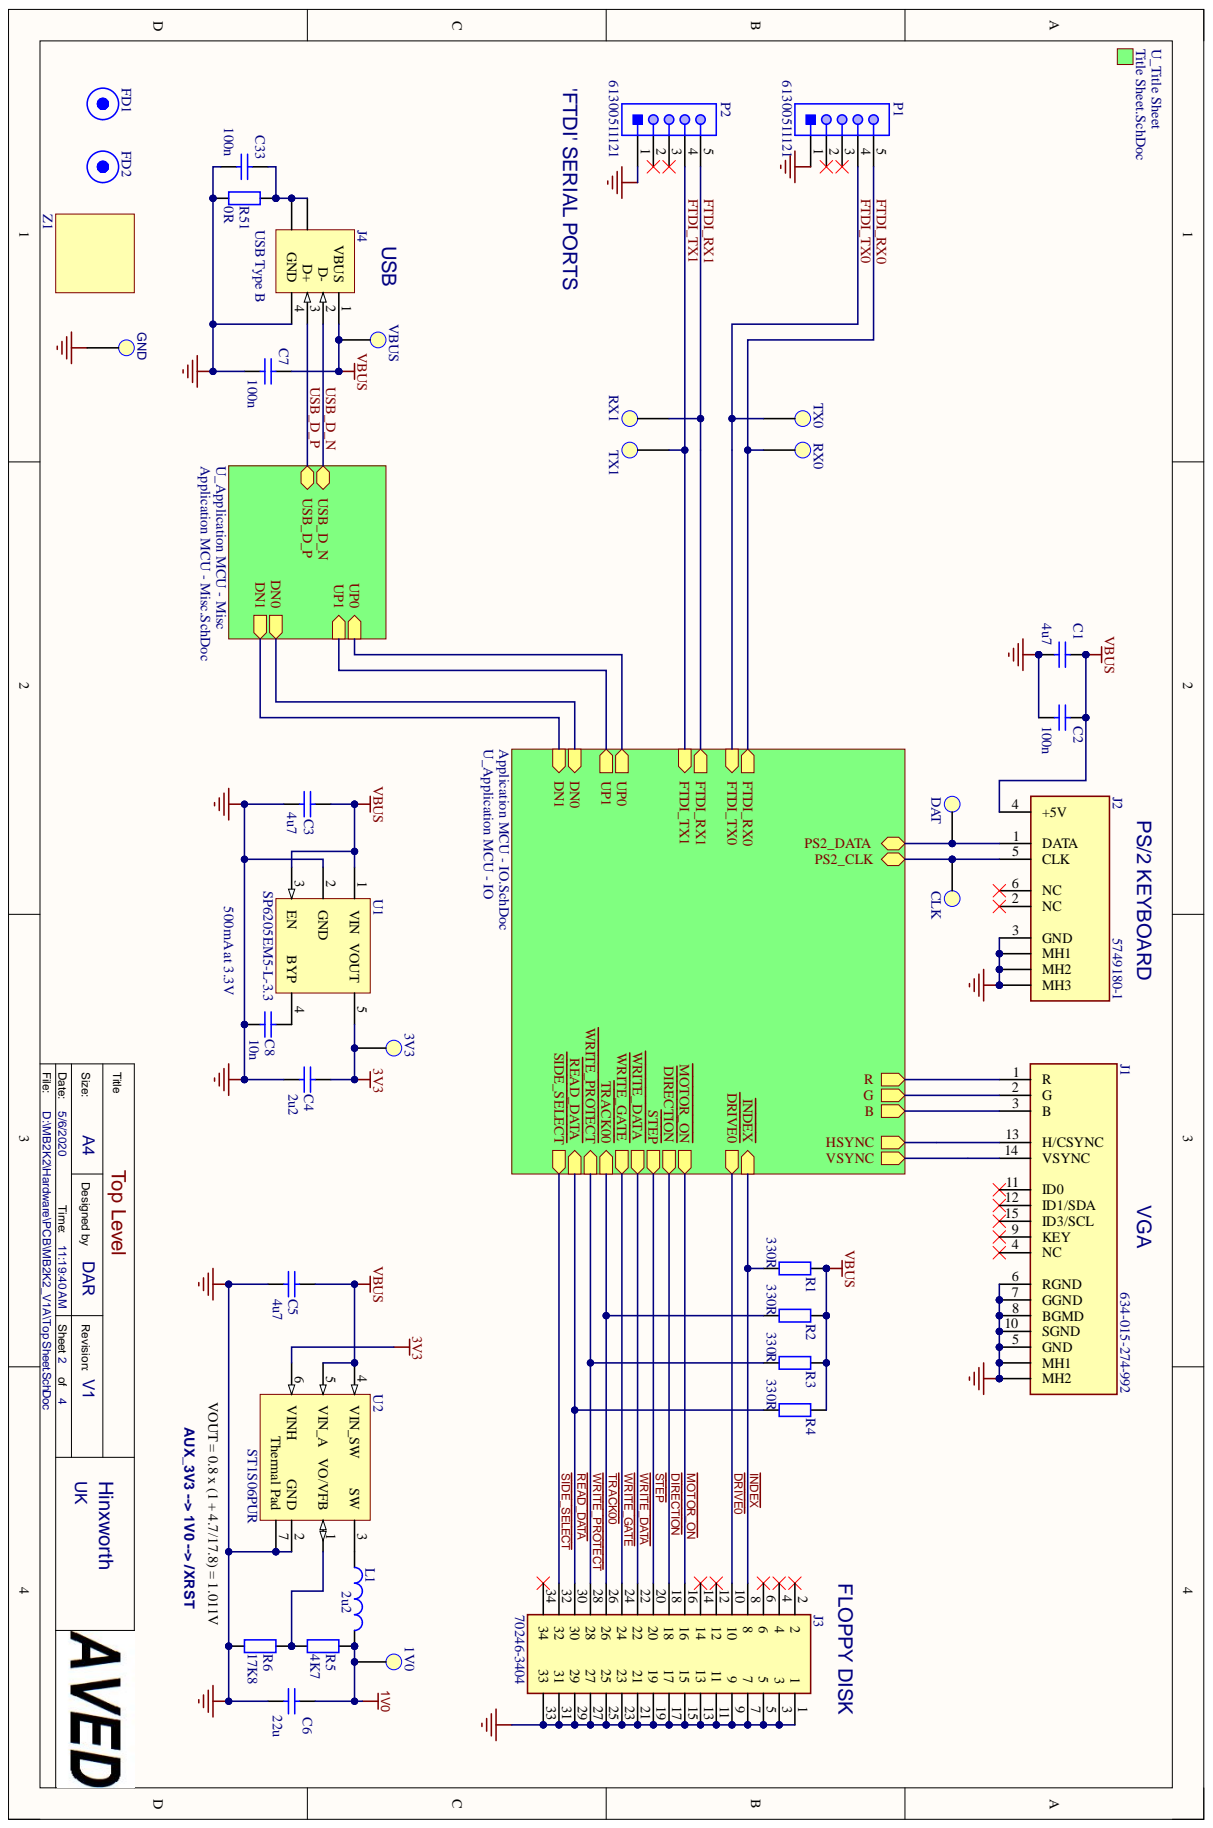
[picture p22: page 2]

Application MCU - Misc.SchDoc

Application MCU - IO.SchDoc

D:\MB2K2\Hardware\PCB\MB2K2_V1A\Top Sheet.SchDoc

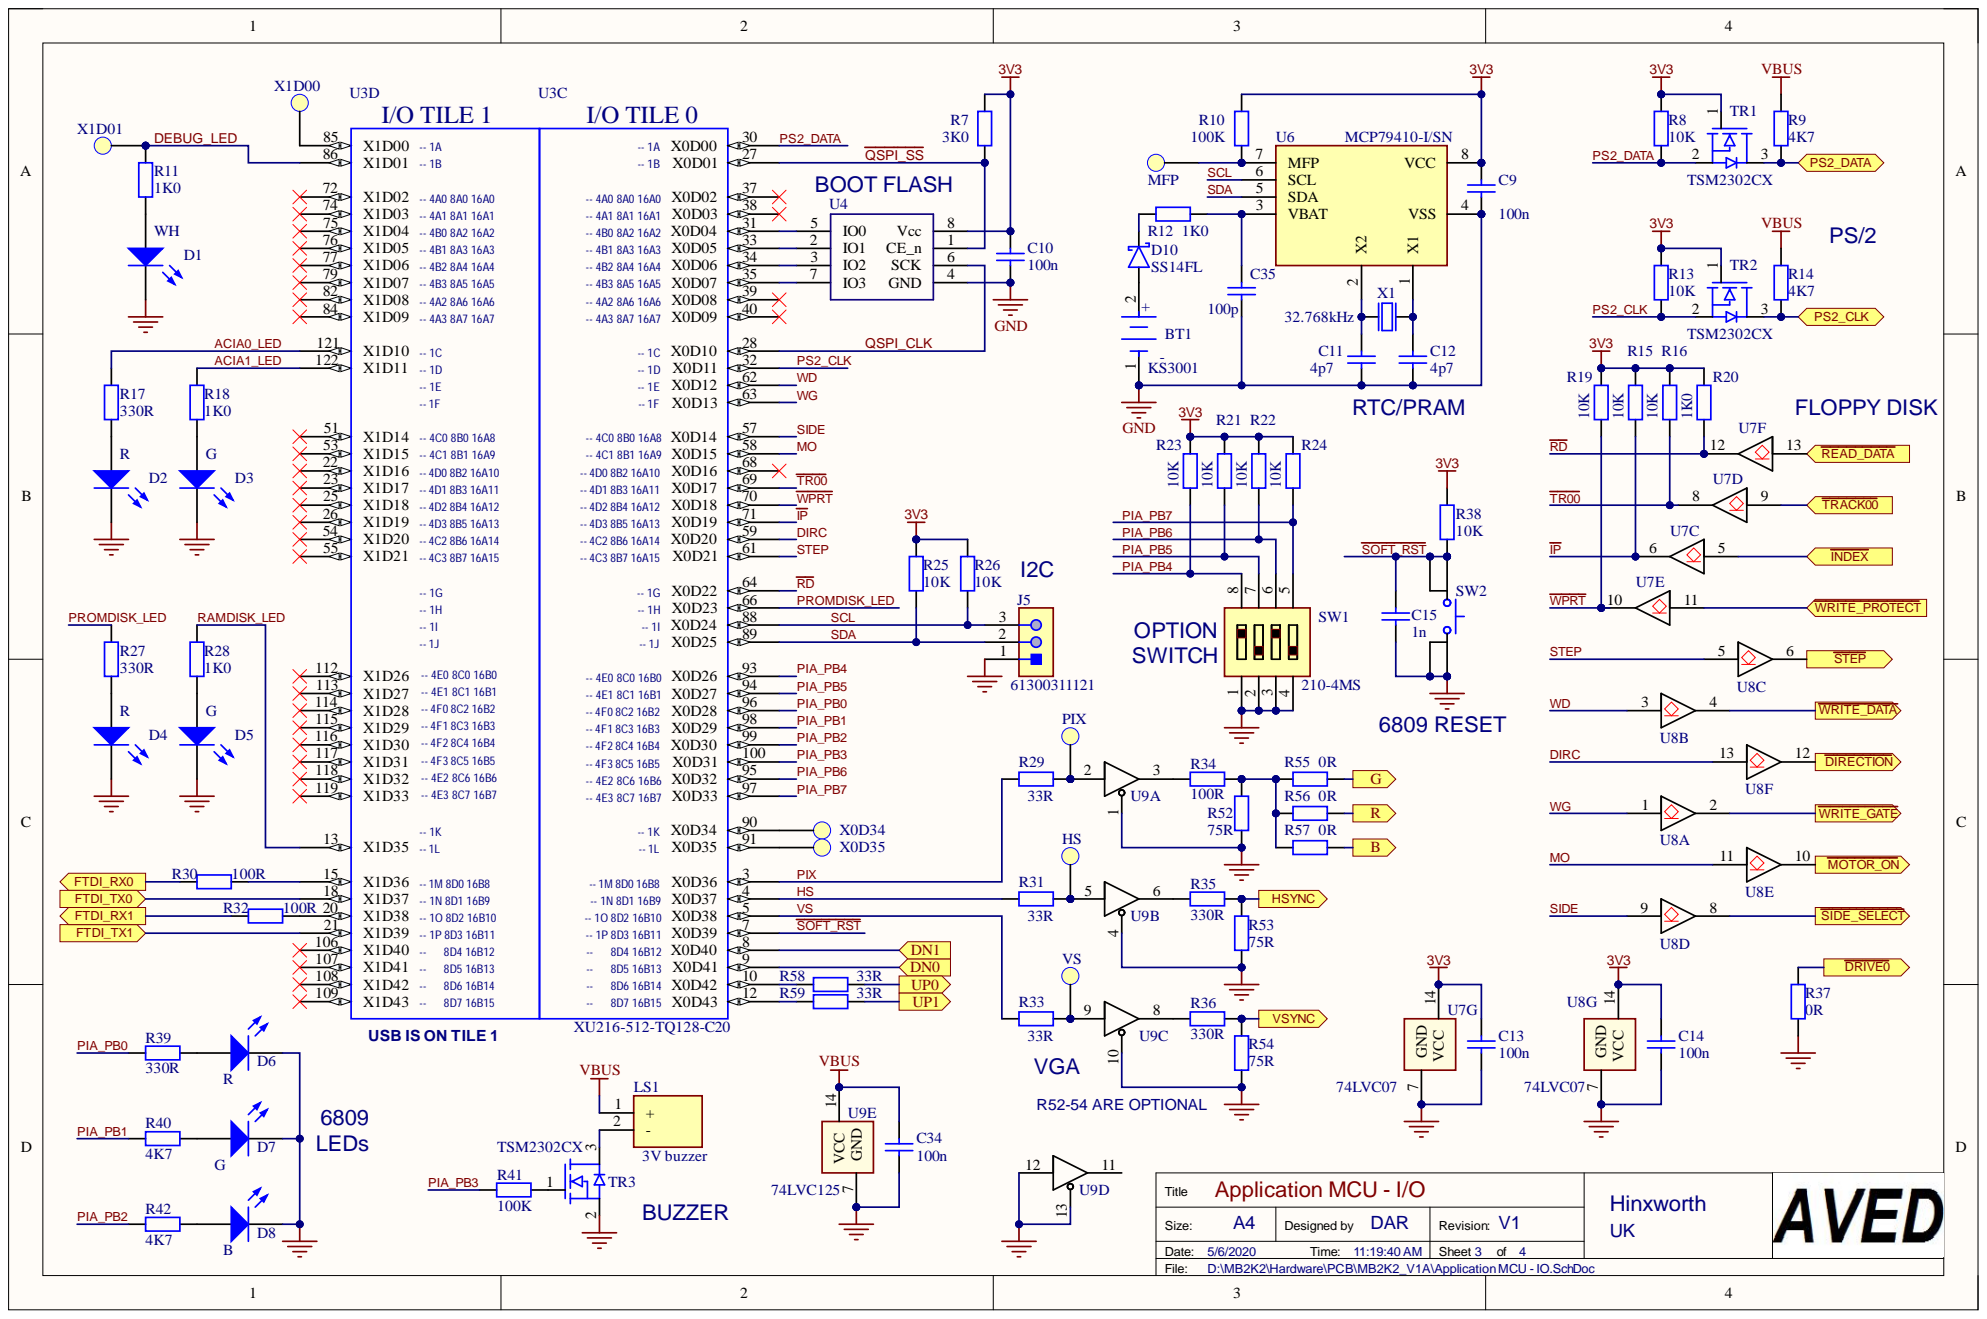
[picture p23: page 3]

X1D02 72 | BOOT FLASH U4

X1D09 84 | | QSPI_CLK

ACIA1_LED | X1D11 122 | | PS2_CLK

X1D33 119 | PIA_PB7 X0D34 X0D35

X1D36 15 | PIX

X1D38 20 | VS
X1D39 21 | | SOFT_RST DN1 DN0

USB IS ON TILE 1

D:\MB2K2\Hardware\PCB\MB2K2_V1A\ApplicationMCU - IO.SchDoc

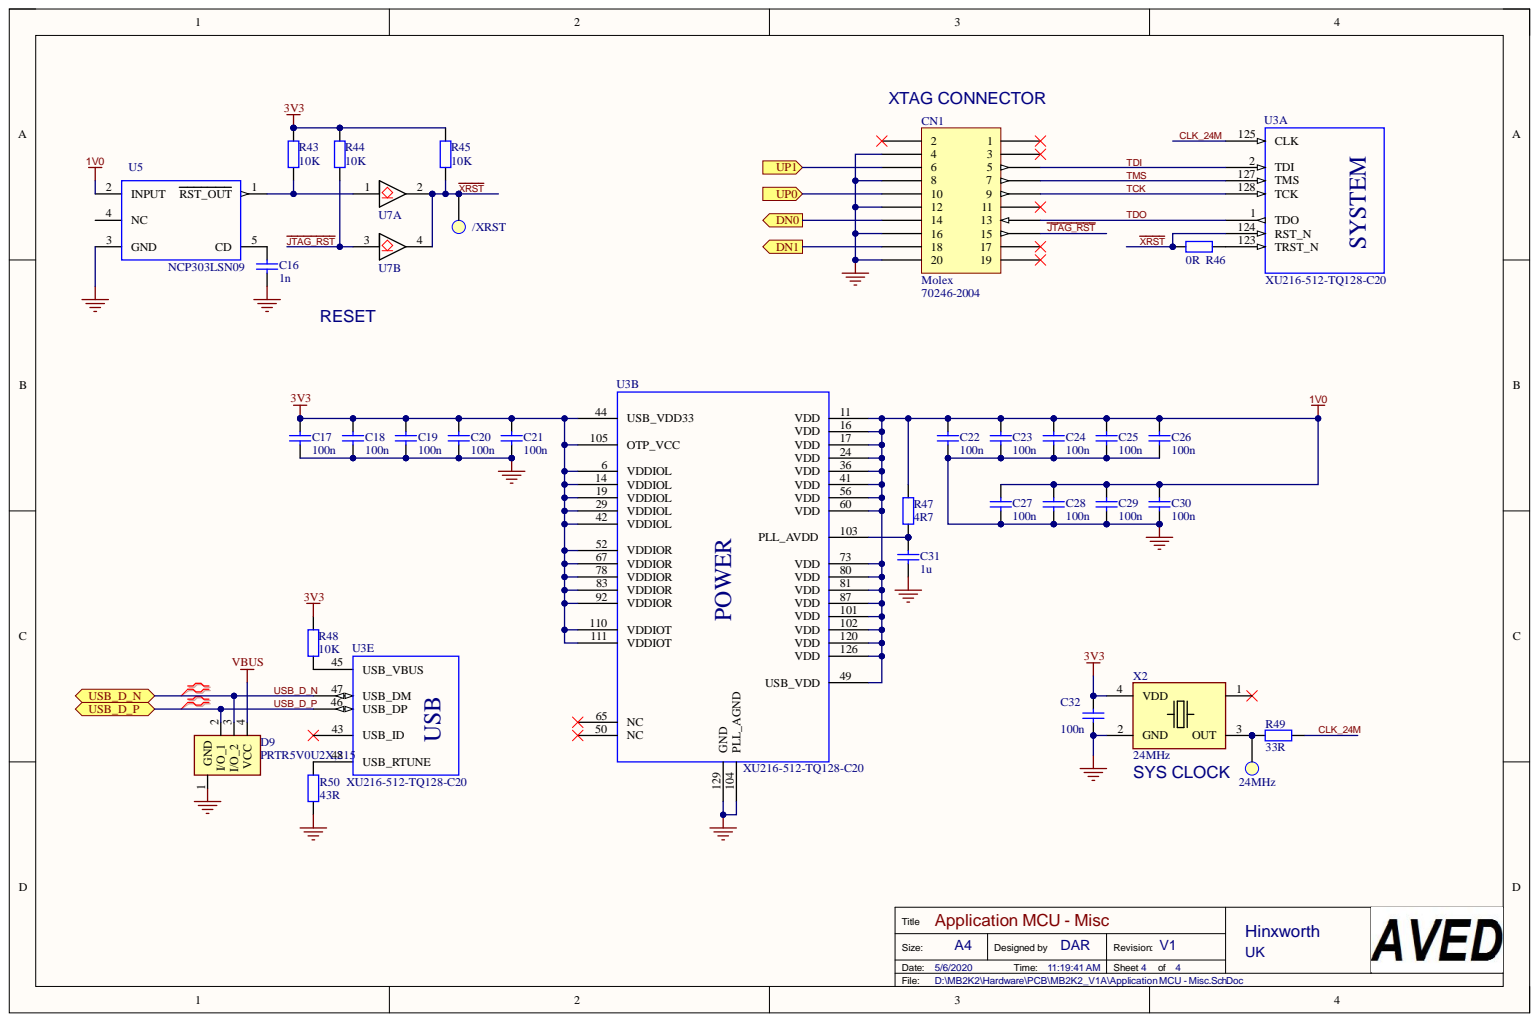
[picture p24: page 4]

D:\MB2K2\Hardware\PCB\MB2K2_V1A\ApplicationMCU - Misc.SchDoc

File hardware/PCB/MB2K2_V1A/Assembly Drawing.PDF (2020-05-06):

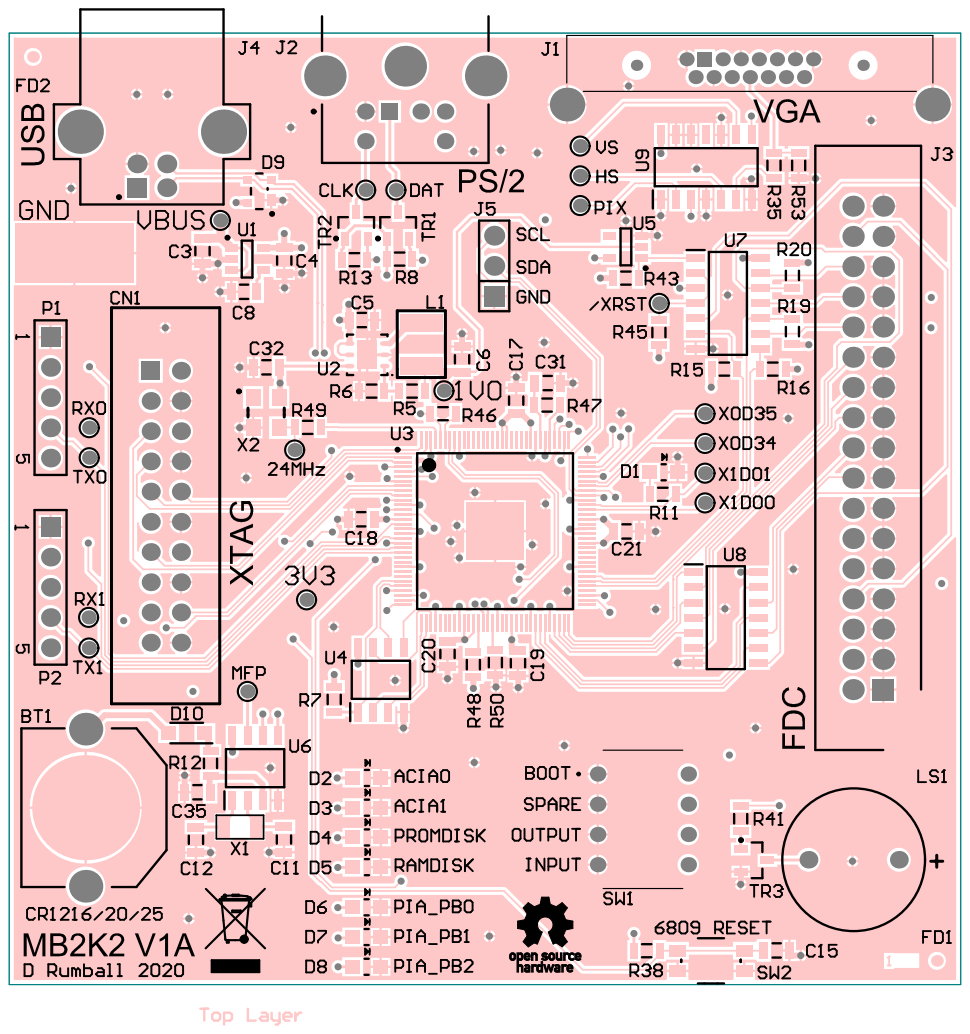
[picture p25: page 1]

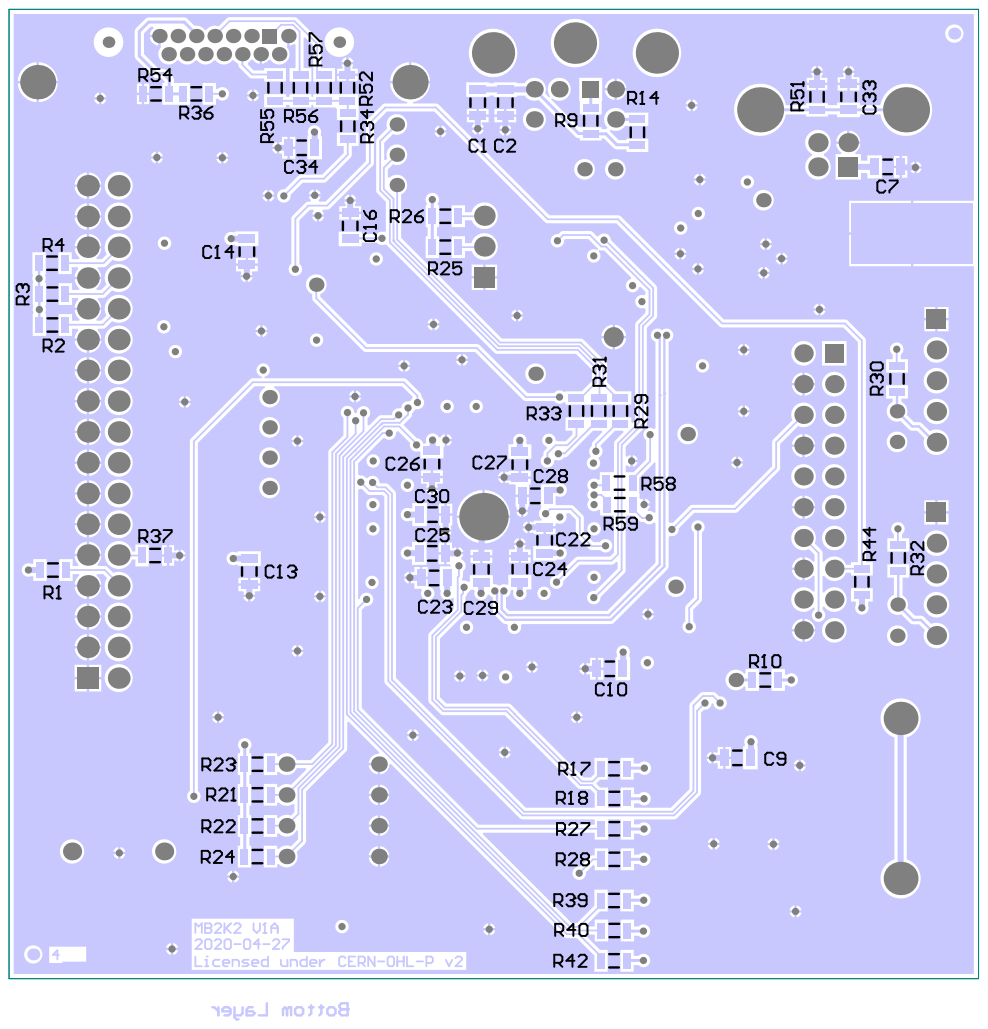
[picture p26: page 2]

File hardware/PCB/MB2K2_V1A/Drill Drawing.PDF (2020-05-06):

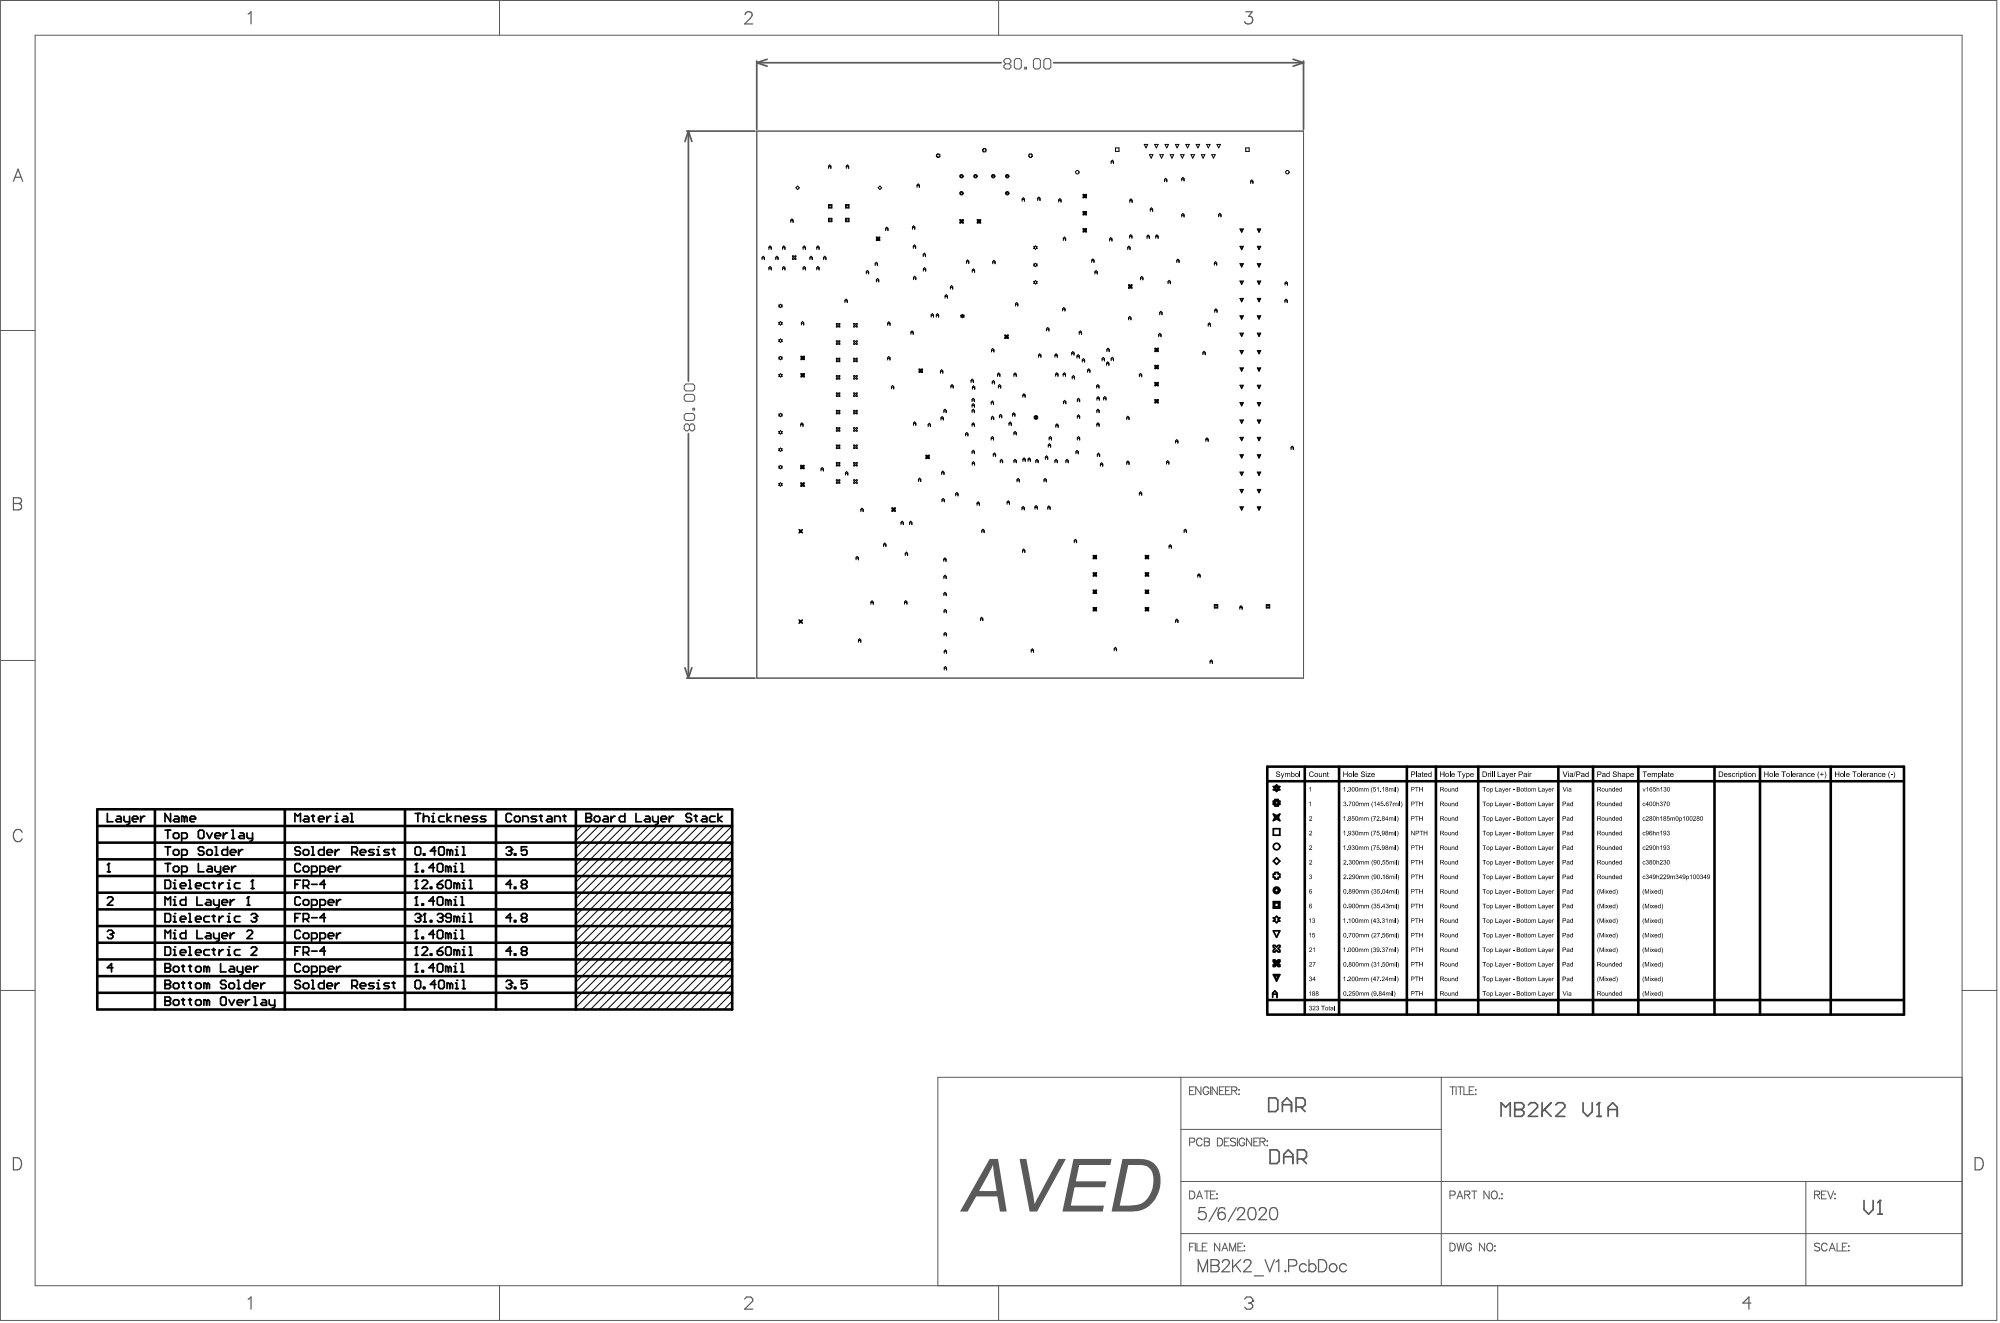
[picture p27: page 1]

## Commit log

2020-05-02 Change to A09 assembler for MON09
2020-05-05 fix BOM and enlarge text on bottom of PCB
    [BOM.xlsx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]
2020-05-06 PCB update to match production and add UART code
    [MB2K2_V1.GBL, MB2K2_V1.GBO, MB2K2_V1.GBP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]
2020-05-15 correct DIP switch ordering
